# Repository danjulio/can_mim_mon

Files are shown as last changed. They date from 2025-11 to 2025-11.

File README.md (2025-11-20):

## CAN MIM MON
Note: I am currently testing this design further.  I saw something that made me wonder if some monitored packets are lost.

CAN Bus Man-in-the-middle monitor for reverse engineering.  Based on the TI [Isolated CAN FD Repeater Reference Design](https://www.ti.com/tool/TIDA-01487) this circuit board is designed to be placed between a CAN Bus and a specific ECU to identify CAN Bus messages originating from that ECU.  It is a CAN Bus repeater with two additional CAN Bus ports to send the bus traffic to an external logging device.  It can also be used as a simple repeater to allow communication with an existing bus without adding a large stub for the external device (allowing it to be remote from the system under study).

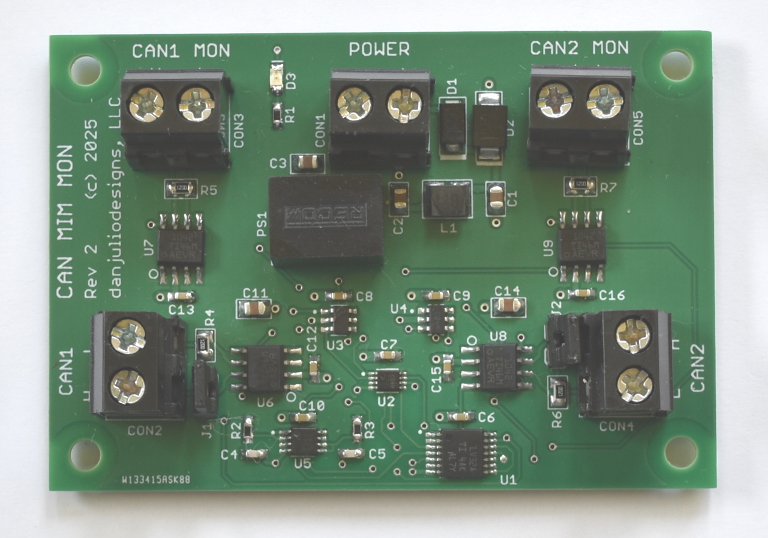
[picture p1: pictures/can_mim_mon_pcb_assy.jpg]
CAN MIM Mon PCB Assembly


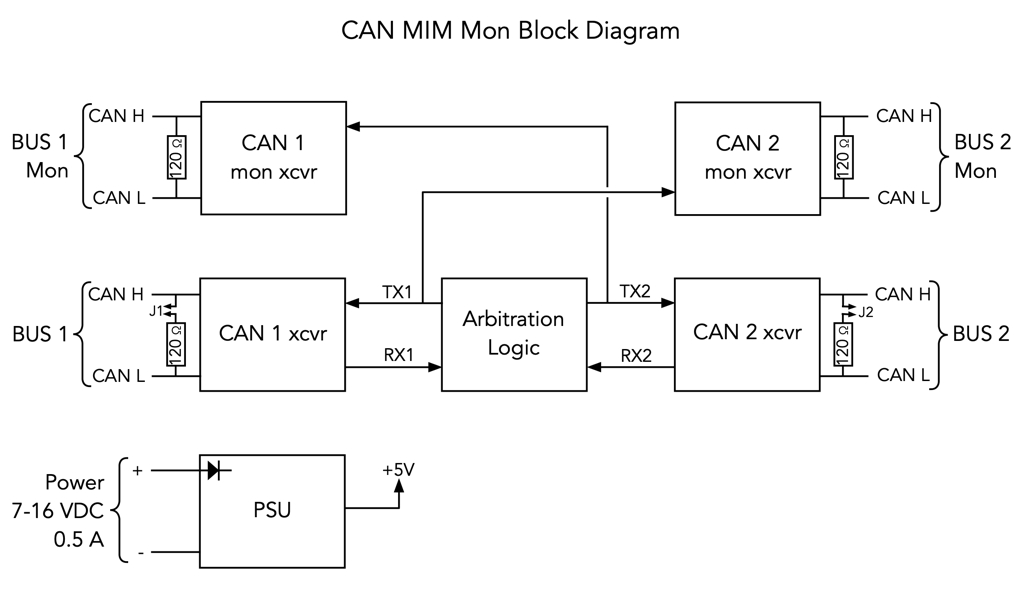
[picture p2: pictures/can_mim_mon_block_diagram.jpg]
CAN MIM Mon Block Diagram


It supports both classic CAN and 2 Mbps CAN FD (untested in my design, but claimed by TI for their circuitry).  It is designed to be powered by a vehicle 12V power supply (7-16 VDC input) with a common ground between CAN devices and the CAN monitoring system.  The power input is reverse-polarity protected.

The CAN1 and CAN2 ports have an optional 120-ohm termination resistor.  The CAN1 MON and CAN2 MON ports have a built-in 120-ohm termination resistor.

This repository contains the gerber files for my Rev 2 PCB.  The file ```documentation/can_mim_mon_loadlist.txt``` contains a simple BOM.  Parts may be ordered from my [Mouser shared project](https://www.mouser.com/Tools/Project/Share?AccessID=fedc605491).

### PCB
The two-sided PCB is 2.75 x 1.9" (69.85 x 48.26mm) and may be ordered as a [PCBWay shared project](https://www.pcbway.com/project/shareproject/CAN_MIM_MON_CAN_Bus_reverse_engineering_interface_41c90bec.html).

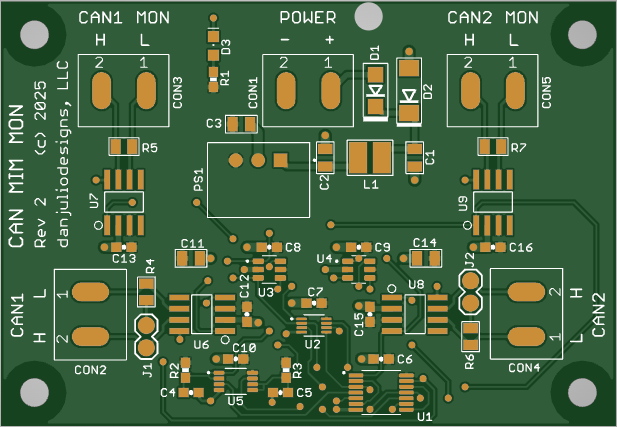
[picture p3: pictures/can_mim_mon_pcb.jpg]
CAN MIM Mon PCB render


### Use Models

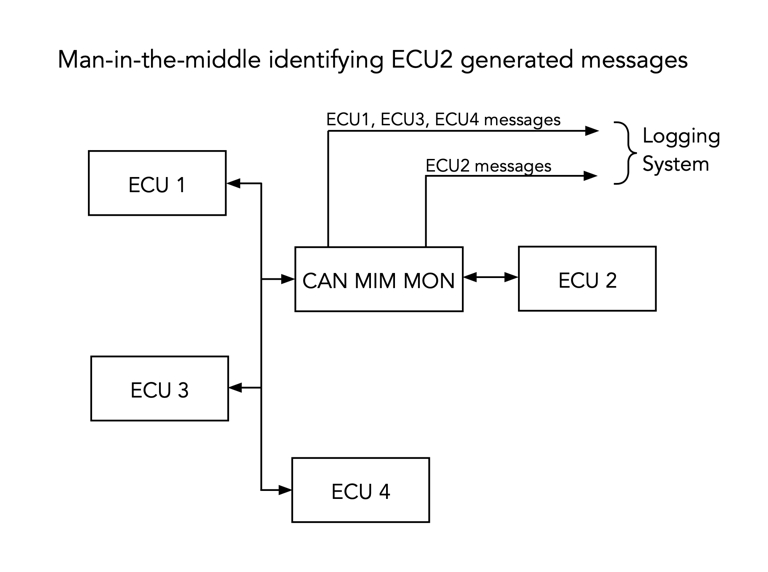
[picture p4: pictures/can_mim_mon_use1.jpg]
CAN MIM MON Isolating ECU traffic


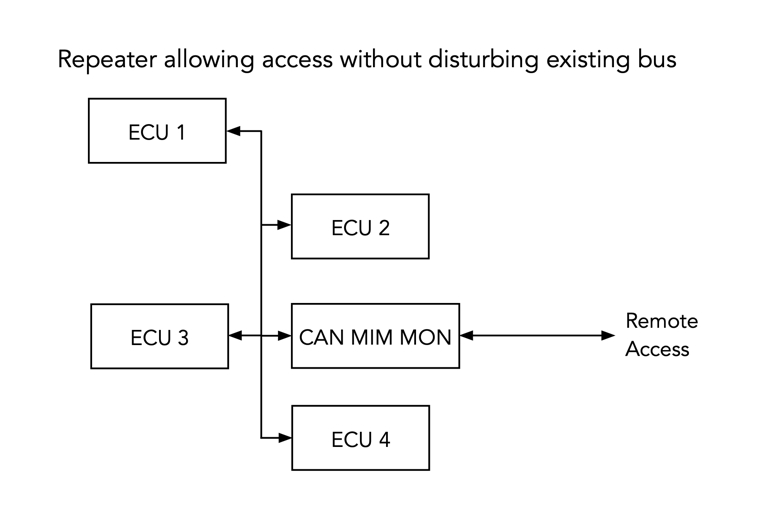
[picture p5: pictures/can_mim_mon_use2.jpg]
CAN MIM MON as a repeater


I initially tested the board as an OBD2 port monitor.  It provides power to the monitoring system from the OBD2 port along with two can busses identifying traffic from an external OBD2 device and the vehicle.

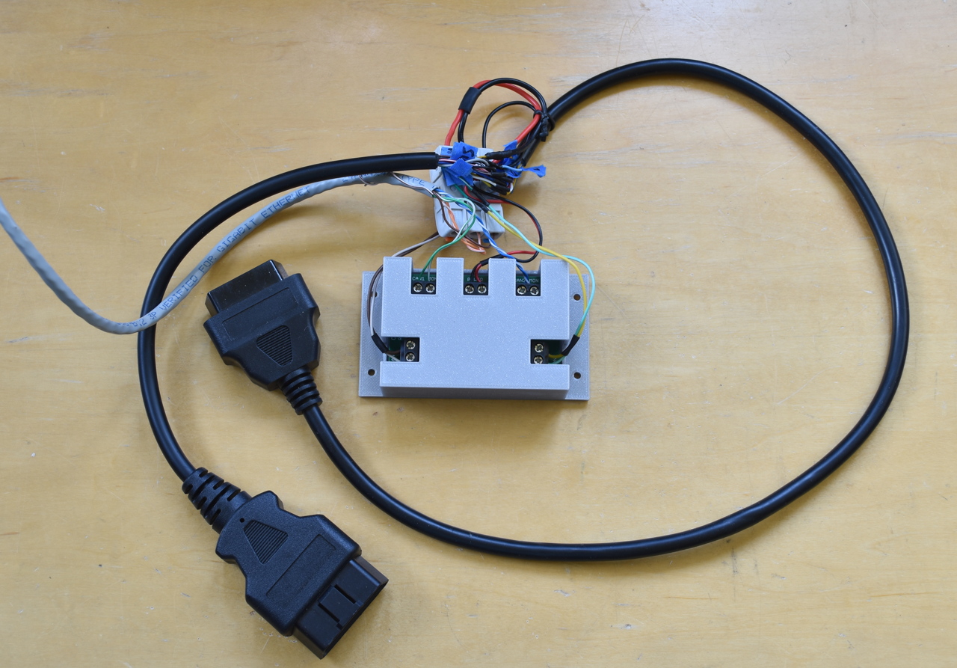
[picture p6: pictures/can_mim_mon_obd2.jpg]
CAN MIM MON OBD2 port monitor


### Theory of Operation
Data is transmitted between CAN1 and CAN2.  As specified in the TI documentation: "The arbitration logic detects which of the two CAN transceivers enter the dominant state first and prevents the loopback of the secondary CAN transceiver side, which would stall the CAN bus into dominant state otherwise".  My addition was another pair of CAN bus transceivers that send the data from each bus to the monitoring system.  Please see the TI document ```tidudb5a.pdf``` at the TI web page above for a detailed theory of operation and simulation results.

Because my schematic was hastily done using off-the-shelf part models, and isn't the clearest, here is the arbitration logic from the TI document using nice old-school logic symbols.

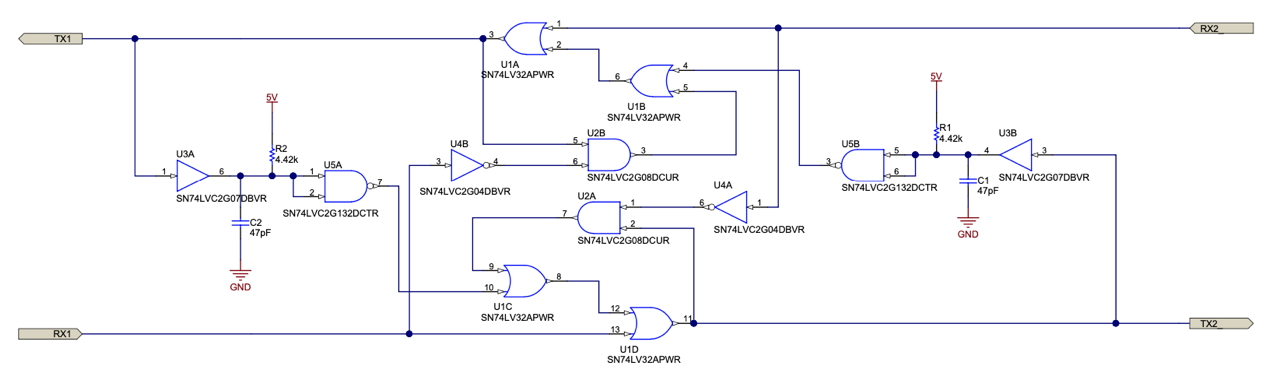
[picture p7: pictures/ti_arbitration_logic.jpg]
TI Arbitration Logic schematic


### 3D printed enclosure
A simple OpenSCAD 3D printed enclosure and associated STL files may be found in the ```enclosure``` sub-directory.  Be sure to slice with supports.

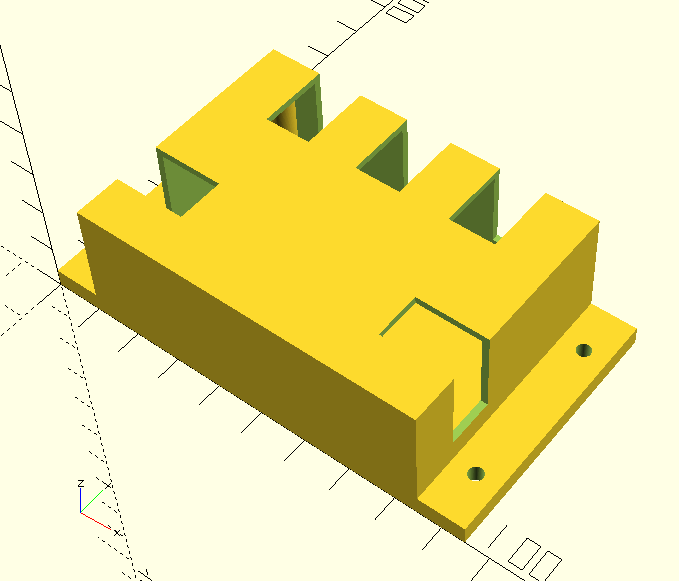
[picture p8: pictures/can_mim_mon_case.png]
Enclosure all-together render


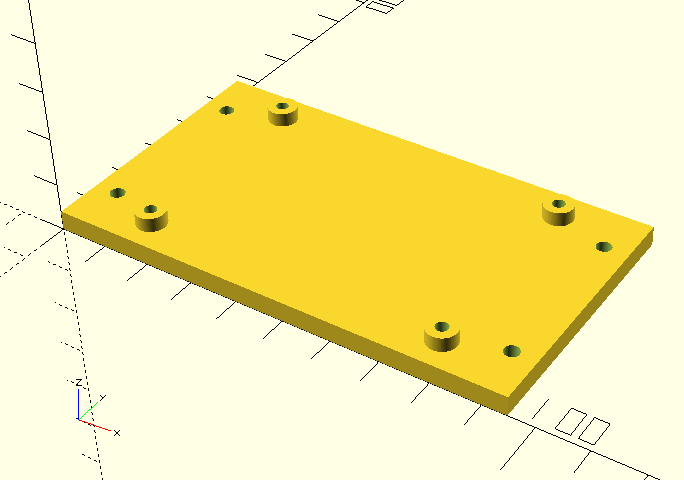
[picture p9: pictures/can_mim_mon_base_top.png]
Enclosure base top view render


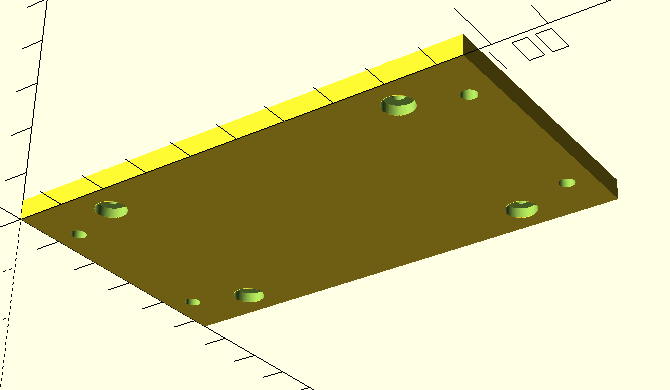
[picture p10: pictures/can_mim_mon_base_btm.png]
Enclosure base bottom view render


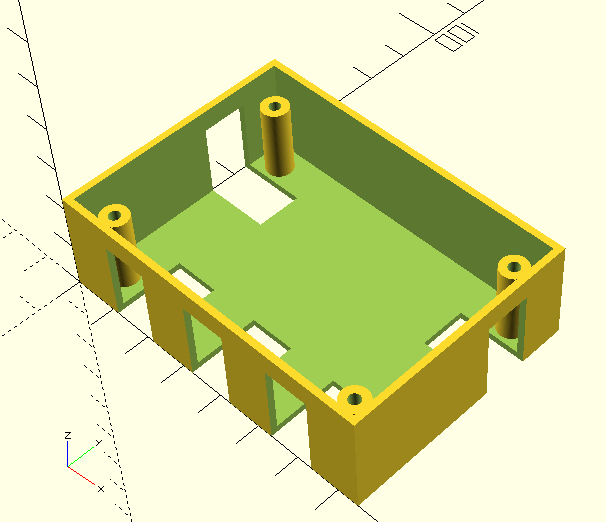
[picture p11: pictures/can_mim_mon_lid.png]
Enclosure lid render


The enclosure is designed for #3 (2.5mm) self-tapping screws.  Sorry I don't have a part number.  I just grabbed from what I had in my screw collection.

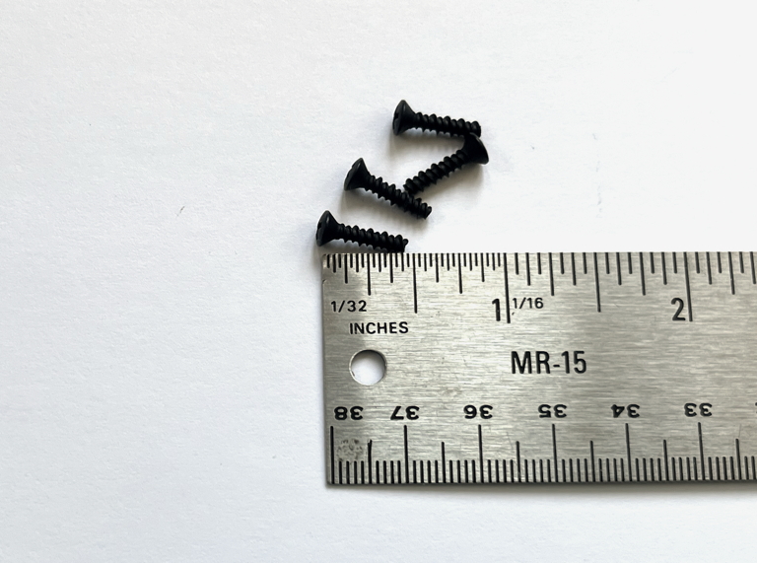
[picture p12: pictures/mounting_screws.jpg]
Mounting screws


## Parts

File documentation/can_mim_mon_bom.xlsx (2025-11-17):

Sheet: CAN MIM MON Rev 2 PCB
CAN MIM MON Rev 2 PCB Specifications
Material | FR4
Layers | 2
Thickness | 1.6 mm
Copper Thickness | 1 oz
Soldermask | Green
Silkscreen | White
Finish | LF HASL
Outer Dimensions | 69.85 x 48.26 mm (2.75 x 1.9”)
Drills | 82

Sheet: CAN MIM MON Rev 2 Top BOM
CAN MIM MON Rev 2 PCB Top side Assembly BOM
Line No | Qty | Ref Desg | Part Number | Manuf | Package/Type | Desc | Distributor Part Number | Notes
1 | 5 | C1, C2, C3, C11, C14 | CL21B106KAYQNNE | Samsung Electro-Mechanics | SMD/0805 | Multilayer Ceramic Capacitors MLCC - SMD/SMT 10uF 25V X7R 10% 080 0805 | Mouser 187-CL21B106KAYQNNE | May substitute with equal or better
2 | 2 | C4, C5 | 885012006021 | Wurth Elektronik | SMD/0603 | Multilayer Ceramic Capacitors MLCC - SMD/SMT WCAP-CSGP 47pF 0603 5% 16V MLCC | Mouser 710-885012006021 | May substitute with equal or better
3 | 9 | C6, C7, C8, C9, C10, C12, C13, C15, C16 | CL10B104KO8NNWC | Samsung Electro-Mechanics | SMD/0603 | Multilayer Ceramic Capacitors MLCC - SMD/SMT 100nF+/-10% 16V X7R 0603 | Mouser 187-CL10B104KO8NNWC | May substitute with equal or better
4 | 5 | CON1, CON2, CON3, CON4, CON5 | 1985946 | Phoenix Contact | TH | Fixed Terminal Blocks MKDSN 2.5/2-5.08 HT | Mouser 651-1985946 | May substitute with equal or better
5 | 1 | D1 | SK14 | Diotec Semiconductor | SMD/DO214AC | Schottky Diodes & Rectifiers Schottky, SMA, 40V, 1A | Mouser 637-SK14 | May substitute with equal or better
6 | 1 | D2 | SMBJ16A | Bourns | SMD/DO214AA | ESD Protection Diodes / TVS Diodes 16volts 5uA 23.1 Amps Uni-Dir | Mouser 652-SMBJ16A | May substitute with equal or better
7 | 1 | D3 | LTST-C171GKT | LITEON | SMD/0805 | Single Color LEDs Green Clear 569nm | Mouser 859-LTST-C171GKT | May substitute with equal or better
8 | 2 | J1, J2 | 5-146282-4 | TE Connectivity | TH | Headers & Wire Housings HDR VT 1X04P .1" 230/090 SN | Mouser 571-5-146282-4 | May substitute with equal or better. These parts must be split into two pieces.
9 | 2 |  | MSBH-G | Adam Tech |  | Headers & Wire Housings HANDLE TOP .100 GOLD PLATED | Mouser 737-MSBH-G | Insert onto J1, J2 after soldering
10 | 1 | L1 | RLS-126-R | RECOM | SMD/4532 | Power Inductors - SMD Line Inductors for RECOM Power Supply | Mouser 919-RLS-126-R
11 | 1 | PS1 | R-78E5.0-0.5 | RECOM | TH | DC/DC Converters - Through Hole 0.5A 5V OUT SIP VERT | Mouser 919-R-78E5.0-0.5 | May substitute with equal or better
12 | 1 | R1 | ERJ-3EKF3300V | Panasonic | SMD/0603 | Thick Film Resistors - SMD 0603 330ohms 1% AEC-Q200 | Mouser 667-ERJ-3EKF3300V | May substitute with equal or better
13 | 2 | R2, R3 | ERJ-3EKF4421V | Panasonic | SMD/0603 | Thick Film Resistors - SMD 0603 4.42Kohms 1% AEC-Q200 | Mouser 667-ERJ-3EKF4421V | May substitute with equal or better
14 | 4 | R4, R5, R6, R7 | ERJ-6ENF1200V | Panasonic | SMD/0805 | Thick Film Resistors - SMD 0805 120ohms 1% AEC-Q200 | Mouser 667-ERJ-6ENF1200V | May substitute with equal or better
15 | 1 | U1 | SN74LV32APWR | Texas Instruments | SMD/SOP65-14 | Logic Gates Quad 2-Input Pos A 595-SN74LV32APW | Mouser 595-SN74LV32APWR | May substitute with equal or better
16 | 1 | U2 | SN74LVC2G08DCURE4 | Texas Instruments | SMD/SOP50-8 | Logic Gates Dual 2-Input Pos A 595-SN74LVC2G08DCUR | Mouser 595-SN74LVC2G08DCUE4 | May substitute with equal or better
17 | 1 | U3 | SN74LVC2G07DBVR | Texas Instruments | SMD/SOT95-6 | Buffers & Line Drivers Dual w/ Open-Drain | Mouser 595-SN74LVC2G07DBVR | May substitute with equal or better
18 | 1 | U4 | SN74LVC2G04DBVR | Texas Instruments | SMD/SOT95-6 | Inverters Dual A 595-SN74LVC2G04DBVT | Mouser 595-SN74LVC2G04DBVR | May substitute with equal or better
19 | 1 | U5 | SN74LVC2G132DCTR | Texas Instruments | SMD/VSSOP8 | Logic Gates Dual 2-Input NAND Gate | Mouser 595-SN74LVC2G132DCTR | May substitute with equal or better
20 | 4 | U6, U7, U8, U9 | TCAN1042HDRQ1 | Texas Instruments | SMD/SO8 | CAN Interface IC Automotive 70-V bus- fault-protected CAN A 595-TCAN1042HDQ1 | Mouser 595-TCAN1042HDRQ1 | May substitute with equal or better

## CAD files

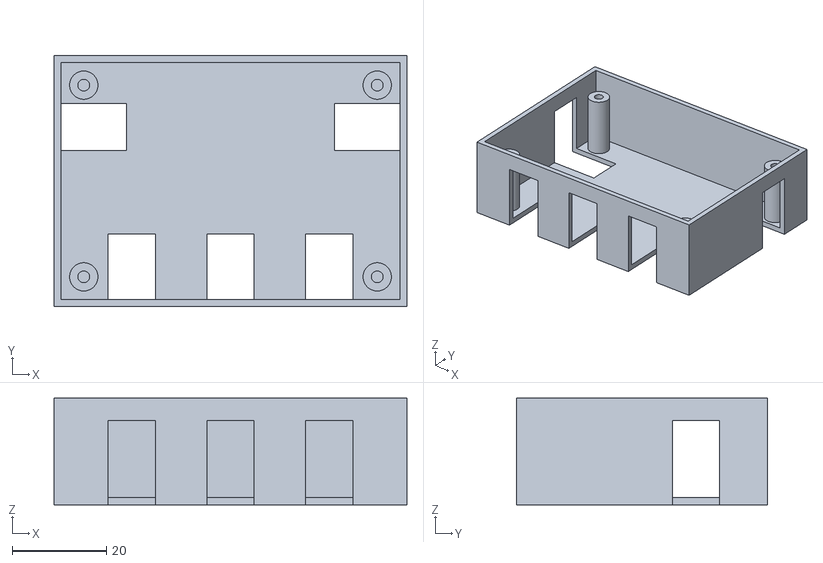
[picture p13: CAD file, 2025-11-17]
enclosure/can_mim_mon_lid.stl
74.8 x 53.3 x 22.6

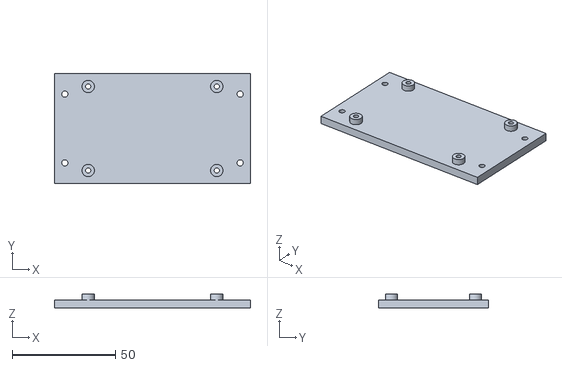
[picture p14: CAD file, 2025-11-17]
enclosure/can_mim_mon_base.stl
94.8 x 53.3 x 7.00

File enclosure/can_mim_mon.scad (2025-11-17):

//
// CAN MIM MON basic two-piece enclosure.  I ain't no mechanical engineer
// so the emphasis is on "basic" ...
//
// Units are mm
//

// ================================================================================
// Set render mode to select which part of the case to display/export
//   1 : Bottom
//   2 : Top
//   3 : Both parts
render = 3;



// ================================================================================
// Enclosure Dimensions
//

pcb_width = 2.75 * 25.4;  // Inches to mm
pcb_depth = 1.9 * 25.4;
pcb_height = 1.6;
pcb_assy_height = 17;      // Components on top

under_pcb_standoff_h = 3;

wall_thickness = 1.5;

mounting_screw_head_d = 6;
mounting_screw_head_h = 2;
mounting_screw_hole_d = 2.5;
standoff_d = mounting_screw_hole_d + 3.5;

enc_width = pcb_width + 2 + 2*wall_thickness;
enc_depth = pcb_depth + 2 + 2*wall_thickness;
enc_base_height = mounting_screw_head_h + 2;
enc_lid_height = under_pcb_standoff_h + pcb_height + pcb_assy_height + 1;

enc_base_wing_hole_d = 3;

// The base is longer than the enclosure for some mounting wings
base_wing_width = 10;
base_width = enc_width + 2 * base_wing_width;
base_screw_delta_x = base_width - base_wing_width; // half-way in wing
base_screw_delta_y = enc_depth - 20;

// PCB Screw mount (PCB is centered)
pcb_screw_delta_w = 2.45 * 25.4;
pcb_screw_delta_d = 1.6 * 25.4;

// Enclosure lid cutouts for wire access
//
// Left and Right
conn_12_x_offset = 0.4 * 25.4;
conn_12_y_offset = 0.5 * 25.4;

// Top Row
conn_3_x_offset = 0.55 * 25.4;
conn_4_x_offset = 1.375 * 25.4;
conn_5_x_offset = 2.2 * 25.4;
cont_345_y_offset = 1.5 * 25.4;

conn_cutout_w = 10;
conn_cutout_d = 13;  // Relative to PCB Edge



// ================================================================================
// Sub-modules
//
module enc_lid_standoff(x, y) {
    height = enc_lid_height - (under_pcb_standoff_h + pcb_height);
    
    translate([x, y, 0]) {
        difference()
        {
            cylinder(d=standoff_d, h=height, $fn=120);
            
            translate([0, 0, height-9]) {
                cylinder(d=mounting_screw_hole_d, h=9.1, $fn=120);
            }
        }
    }
}


//
// orientation = 1 for left side
// orientation = 2 for right side
// orientation = 3, 4, 5 for top row
module enc_lid_conn_cutout(orientation) {
    h = enc_lid_height - (pcb_height + under_pcb_standoff_h);
    
    if (orientation == 1) {
        x = -0.1;
        y = enc_depth - (enc_depth - pcb_depth)/2 - (conn_12_y_offset + conn_cutout_w/2);
        w = (enc_width - pcb_width)/2 + conn_cutout_d;
        d = conn_cutout_w;
        
        translate([x, y, -0.1]) {
            cube([w, d, h]);
        }
    }
    
    if (orientation == 2) {
        x = enc_width - (enc_width - pcb_width)/2 - conn_cutout_d + 0.1;
        y = enc_depth - (enc_depth - pcb_depth)/2 - (conn_12_y_offset + conn_cutout_w/2);
        w = (enc_width - pcb_width)/2 + conn_cutout_d;
        d = conn_cutout_w;
        
        translate([x, y, -0.1]) {
            cube([w, d, h]);
        }
    }
    
    if (orientation == 3) {
        x = (enc_width - pcb_width)/2 + (conn_3_x_offset - conn_cutout_w/2);
        y = -0.1;
        w = conn_cutout_w;
        d = (enc_depth - pcb_depth)/2 + conn_cutout_d;
        
        translate([x, y, -0.1]) {
            cube([w, d, h]);
        }
    }
    
    if (orientation == 4) {
        x = (enc_width - pcb_width)/2 + (conn_4_x_offset - conn_cutout_w/2);
        y = -0.1;
        w = conn_cutout_w;
        d = (enc_depth - pcb_depth)/2 + conn_cutout_d;
        
        translate([x, y, -0.1]) {
            cube([w, d, h]);
        }
    }
    
    if (orientation == 5) {
        x = (enc_width - pcb_width)/2 + (conn_5_x_offset - conn_cutout_w/2);
        y = -0.1;
        w = conn_cutout_w;
        d = (enc_depth - pcb_depth)/2 + conn_cutout_d;
        
        translate([x, y, -0.1]) {
            cube([w, d, h]);
        }
    }
}



// ================================================================================
// Components
//
module base() {
    difference() {
        union() {
            // Base
            cube([base_width, enc_depth, enc_base_height]);
            
            // Standoffs
            translate([base_wing_width, 0, -0.1]) {
                x = (enc_width - pcb_screw_delta_w) / 2;
                y = (enc_depth - pcb_screw_delta_d) / 2;
                translate([x, y, 0]) {
                    cylinder(d=standoff_d, h=enc_base_height+under_pcb_standoff_h, $fn=120);
                }
                 translate([x + pcb_screw_delta_w, y, 0]) {
                    cylinder(d=standoff_d, h=enc_base_height+under_pcb_standoff_h, $fn=120);
                }
                translate([x, y + pcb_screw_delta_d, 0]) {
                    cylinder(d=standoff_d, h=enc_base_height+under_pcb_standoff_h, $fn=120);
                }
                 translate([x + pcb_screw_delta_w, y + pcb_screw_delta_d, 0]) {
                    cylinder(d=standoff_d, h=enc_base_height+under_pcb_standoff_h, $fn=120);
                }
            }
        }
        
        // Base wing screw holes
        x = base_wing_width/2;
        y = (enc_depth - base_screw_delta_y)/2;
        translate([x, y, -0.1]) {
            cylinder(d=enc_base_wing_hole_d, h=enc_base_height + 0.2, $fn=120);
        }
        translate([x, y + base_screw_delta_y, -0.1]) {
            cylinder(d=enc_base_wing_hole_d, h=enc_base_height + 0.2, $fn=120);
        }
        translate([x + base_screw_delta_x, y, -0.1]) {
            cylinder(d=enc_base_wing_hole_d, h=enc_base_height + 0.2, $fn=120);
        }
        translate([x + base_screw_delta_x, y + base_screw_delta_y, -0.1]) {
            cylinder(d=enc_base_wing_hole_d, h=enc_base_height + 0.2, $fn=120);
        }
        
        // Enclosure lid screw holes
        translate([base_wing_width, 0, -0.1]) {
            x = (enc_width - pcb_screw_delta_w) / 2;
            y = (enc_depth - pcb_screw_delta_d) / 2;
            translate([x, y, -0.1]) {
                // Screw head hole
                cylinder(d=mounting_screw_head_d, h=mounting_screw_head_h+0.1, $fn=120);
                
                // Screw hole
                cylinder(d=mounting_screw_hole_d, h=enc_base_height+under_pcb_standoff_h+0.2, $fn=120);
            }
            translate([x + pcb_screw_delta_w, y, -0.1]) {
                cylinder(d=mounting_screw_head_d, h=mounting_screw_head_h+0.1, $fn=120);
                cylinder(d=mounting_screw_hole_d, h=enc_base_height+under_pcb_standoff_h+0.2, $fn=120);
            }
            translate([x, y + pcb_screw_delta_d, -0.1]) {
                cylinder(d=mounting_screw_head_d, h=mounting_screw_head_h+0.1, $fn=120);
                cylinder(d=mounting_screw_hole_d, h=enc_base_height+under_pcb_standoff_h+0.2, $fn=120);
            }
            translate([x + pcb_screw_delta_w, y + pcb_screw_delta_d, -0.1]) {
                cylinder(d=mounting_screw_head_d, h=mounting_screw_head_h+0.1, $fn=120);
                cylinder(d=mounting_screw_hole_d, h=enc_base_height+under_pcb_standoff_h+0.2, $fn=120);
            }
        }
    }
}


module lid() {
    difference() {
        union() {
            // Hollow Box
            difference() {
                cube([enc_width, enc_depth, enc_lid_height]);
                
                translate([wall_thickness, wall_thickness, wall_thickness]) {
                    cube([enc_width - 2 * wall_thickness, enc_depth - 2 * wall_thickness, enc_lid_height]);
                }
            }
            
            // Standoffs
            x = (enc_width - pcb_screw_delta_w) / 2;
            y = (enc_depth - pcb_screw_delta_d) / 2;
            enc_lid_standoff(x, y);
            enc_lid_standoff(x + pcb_screw_delta_w, y);
            enc_lid_standoff(x, y + pcb_screw_delta_d);
            enc_lid_standoff(x + pcb_screw_delta_w, y + pcb_screw_delta_d);
        }
        
        // Cutouts for access to connectors
        enc_lid_conn_cutout(1);
        enc_lid_conn_cutout(2);
        enc_lid_conn_cutout(3);
        enc_lid_conn_cutout(4);
        enc_lid_conn_cutout(5);
    }
}



// ================================================================================
// Render control
//

if (render == 1) {
    base();
}

if (render == 2) {
    lid();
}

if (render == 3) {
    base();
    
    translate([base_wing_width, enc_depth, enc_base_height + enc_lid_height]) {
        rotate([180, 0, 0]) {
            lid();
        }
    }
}

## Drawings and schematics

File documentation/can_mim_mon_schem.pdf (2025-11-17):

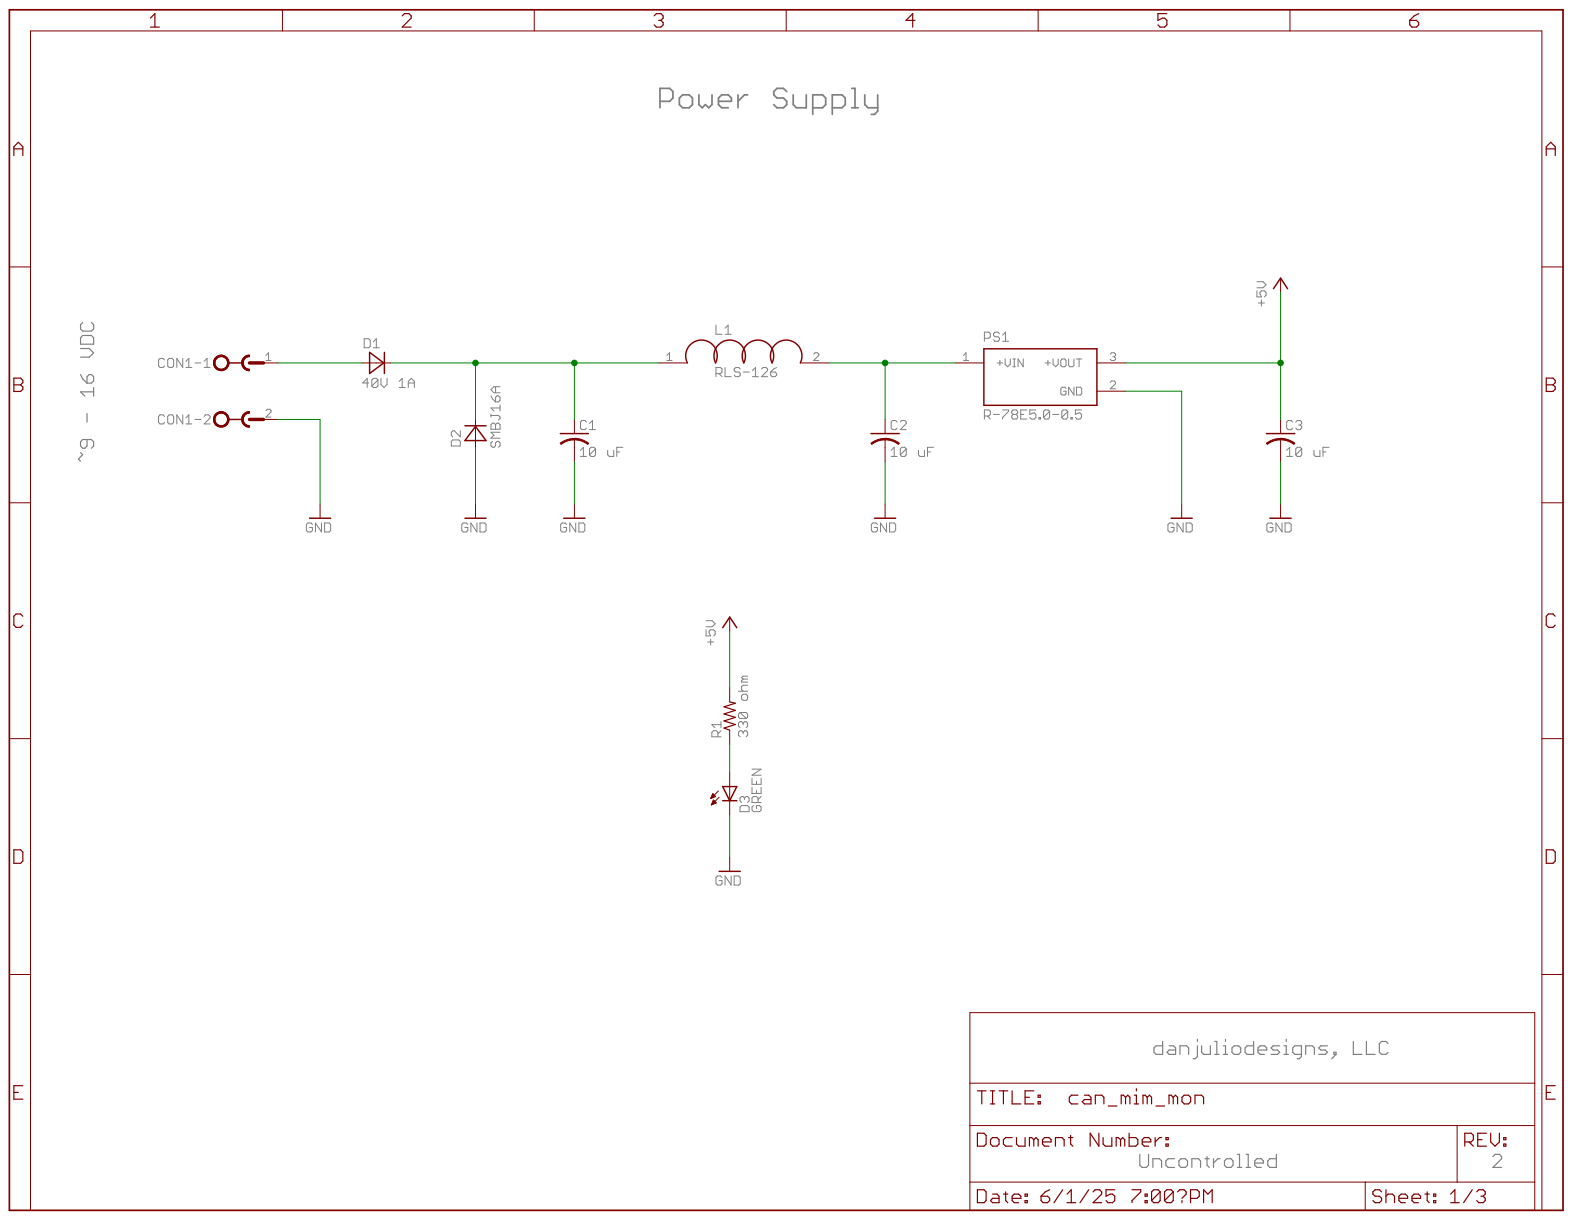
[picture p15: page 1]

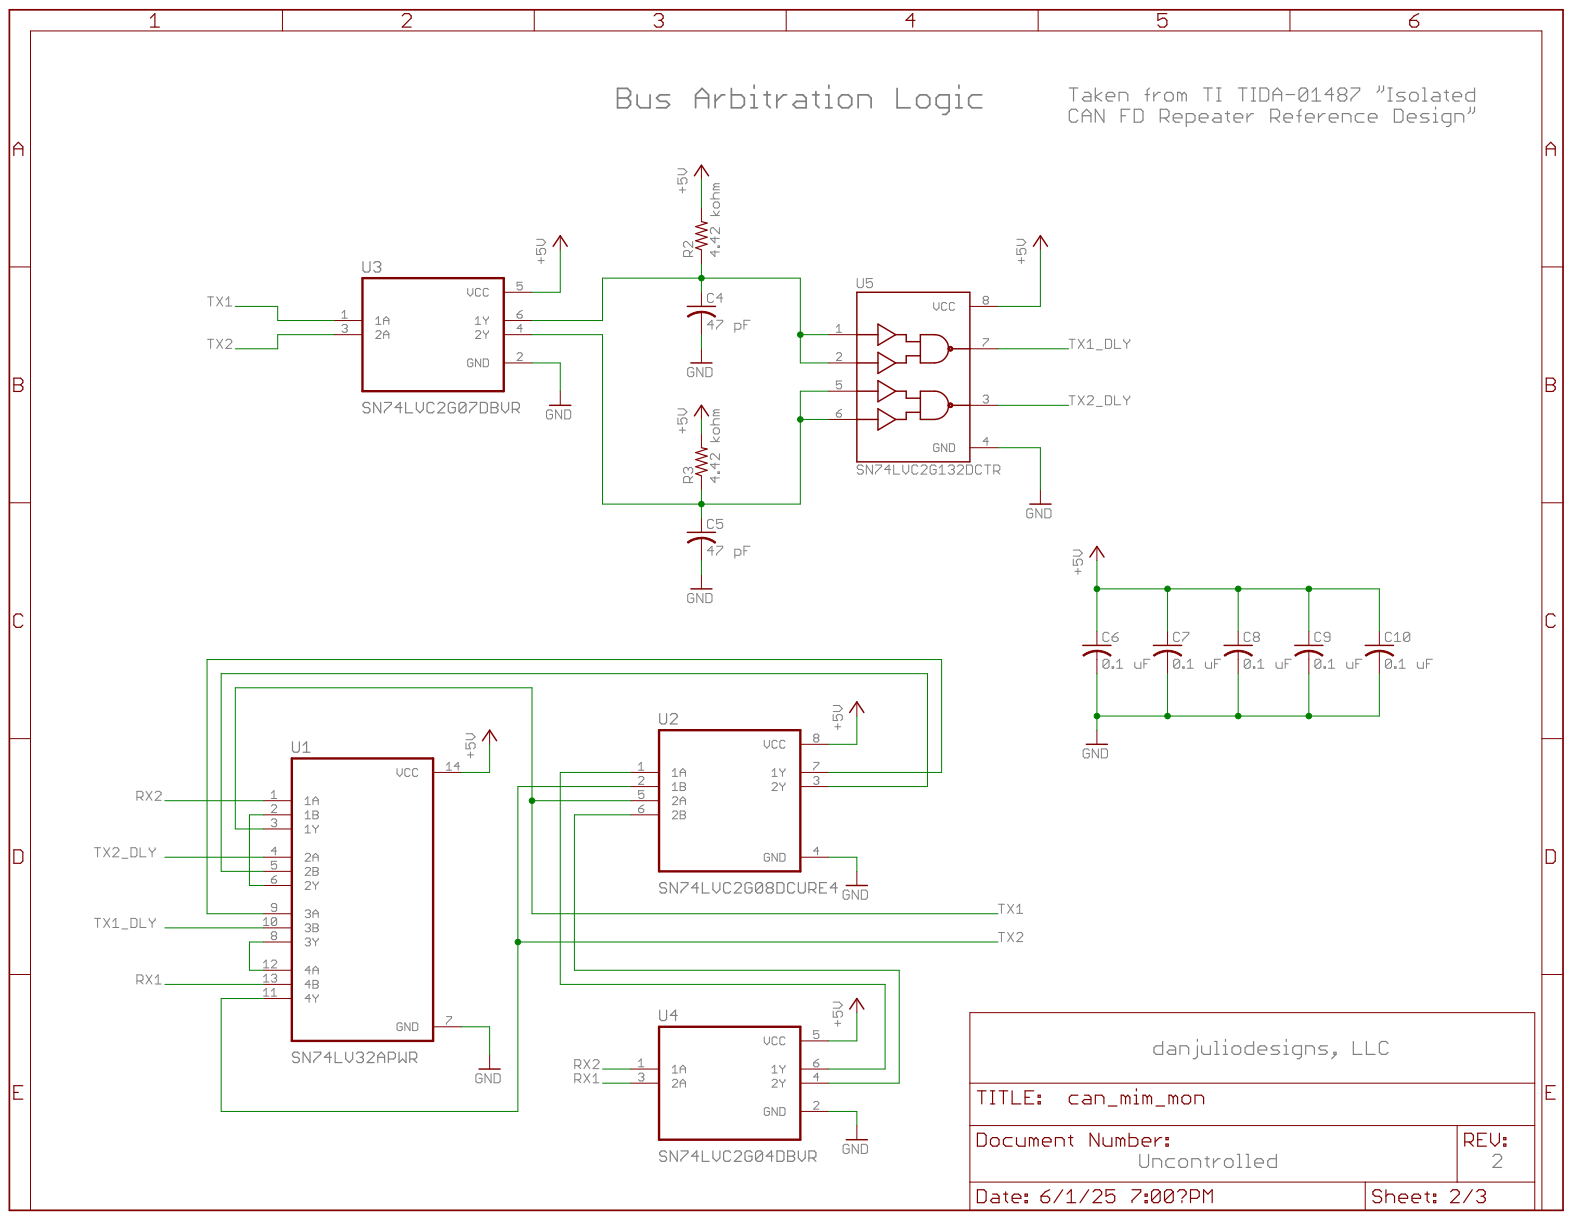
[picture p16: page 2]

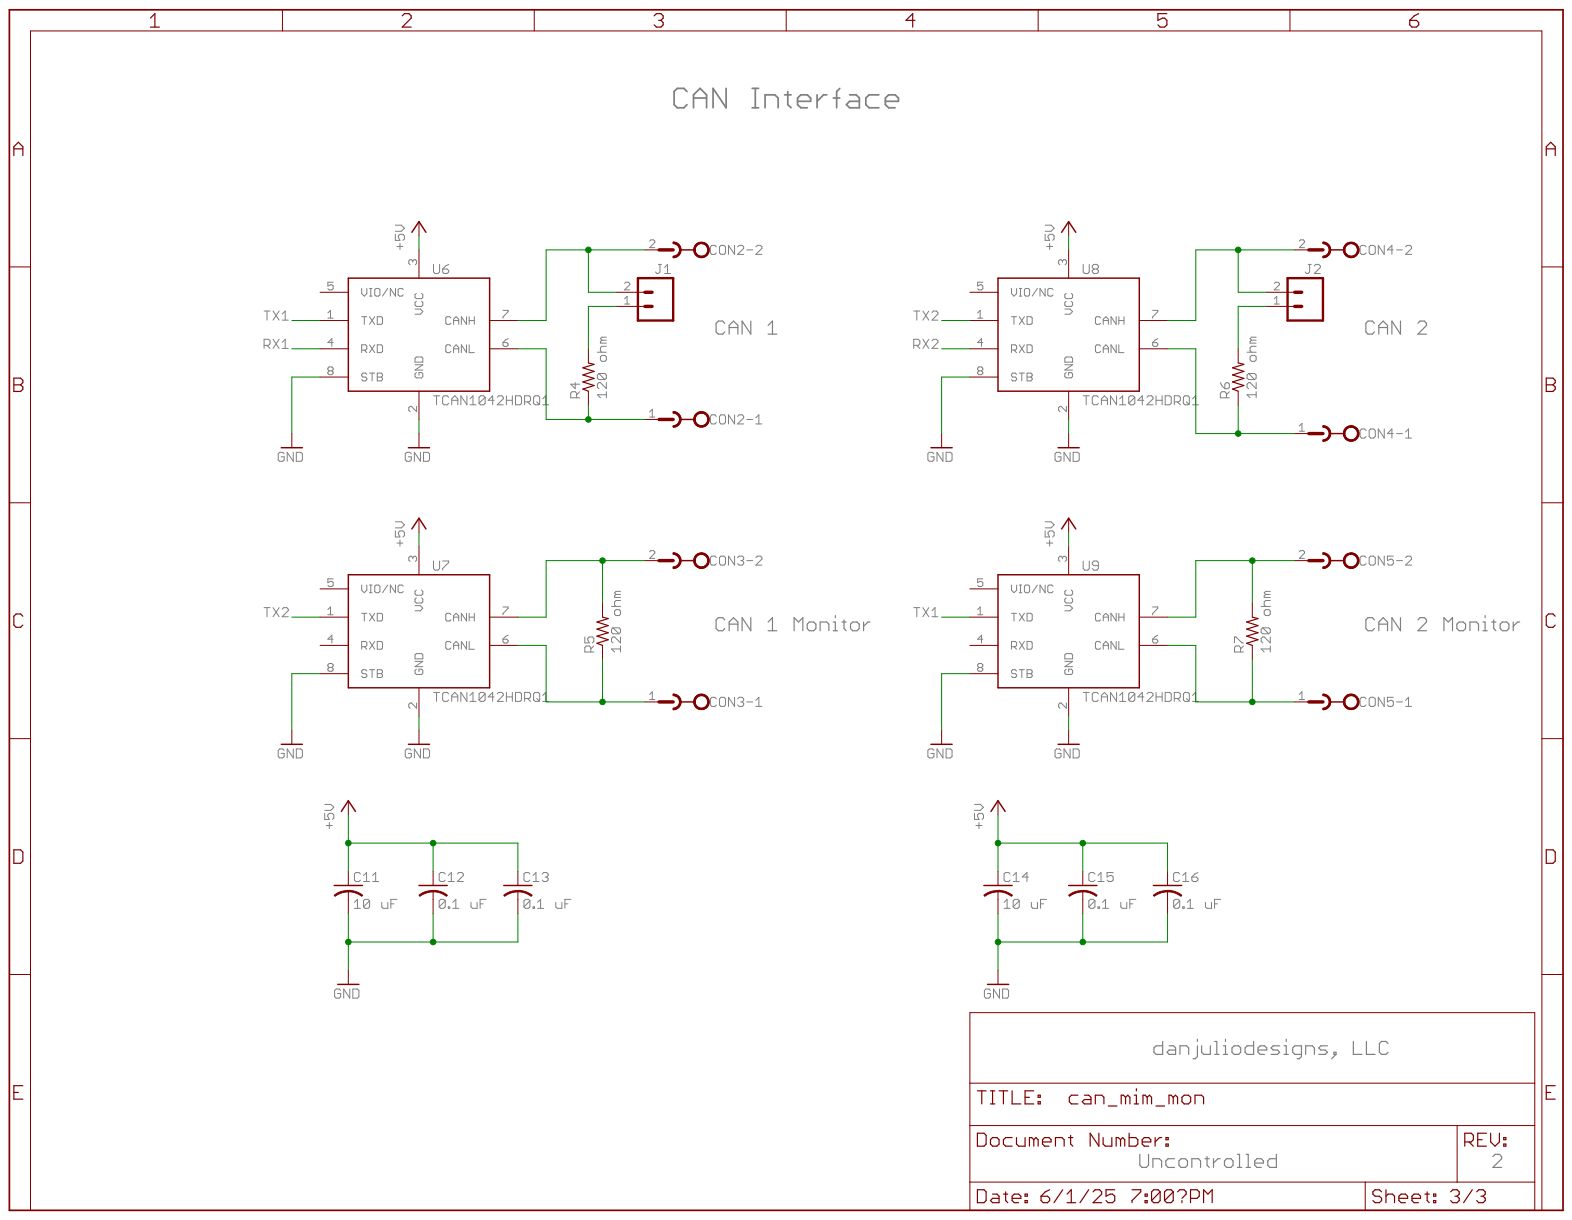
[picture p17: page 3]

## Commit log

2025-11-17 Add content
    [can_mim_mon.scad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]
2025-11-17 Add PCBWay shared project link
